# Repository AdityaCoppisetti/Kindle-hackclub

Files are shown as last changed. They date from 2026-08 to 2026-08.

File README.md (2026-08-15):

hey im dhruv coppisetti and i built my own kindle from scratch using a e ink display and my own custom pcb i designed!
i absolutely love e ink displays and have been wanting to build my own kindle from a very long time. 
i dont want something thats too fancy or has too much, a simple kindle type design works aswell.

i love reading books and with all the travelling that im doing, i havent been able to carry my books and i know i could 
just download books on my phone and read them that way but i am just a sucker for single purpose technology. 
and its just so amazing building your own devices and with the hackclub's macondo program i thought i should make this and so i did. 
before this i havent really made much without using what was in my arduino kit. so in this project, i learnt along the way whatever it took me to make this 
and you can learn aswell from my journal.md in this project , i go over almost everything

here is how the kindle i designed looks like 

Screenshot From 2026-08-15 14-37-48

Screenshot From 2026-08-15 14-38-00

Screenshot From 2026-08-15 14-38-12

 i need to answer some questions to explain further why i built this 

1) why am i making this?
  this is a device for students and avid readers like me who want a distraction free reading device     with a long battery life and its open sourced.

2) what makes it different from a kindle?
  its fully open sourced hardware and firmware , its extremely repairable , expandable with a microsd card with customizable software and a secondary oled status display for battery , page nuber and reading progress.

 3) display size - 4.2 inch e ink display 
 4) battery life- target of 3 to 6 weeks of normal reading with aggressive deep sleep and infrequent e ink refreshes
 5) linux or bare metal?
    bare metal sice im using an esp32-c3 ( arduino framework with platformIO) this provides much
    lower power consumption and faster startup than linux
6) touchscreen? no physical buttons only for a distraction free reading
experience and improved battery life.

for this project ill be making my own custom esp32 powered pcb 

which looks like this -





it took me multiple versions of the pcb to come to this point you can find all of that in my journal.md 

here is how the pcb looks like in kicad's 3d viewer





and obviously here is a lil 360 

https://github.com/user-attachments/assets/d5890601-8e93-464f-907f-b951f2e43e23

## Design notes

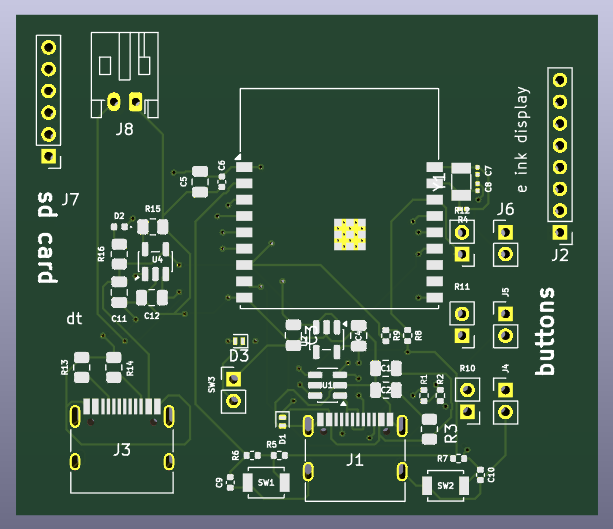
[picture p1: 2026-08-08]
Screenshot From 2026-08-08 19-58-43.png

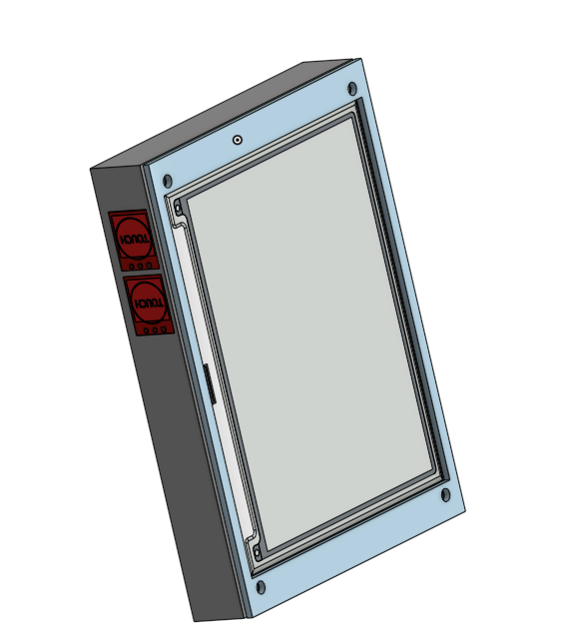
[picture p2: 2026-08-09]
Screenshot From 2026-08-09 17-33-04.png

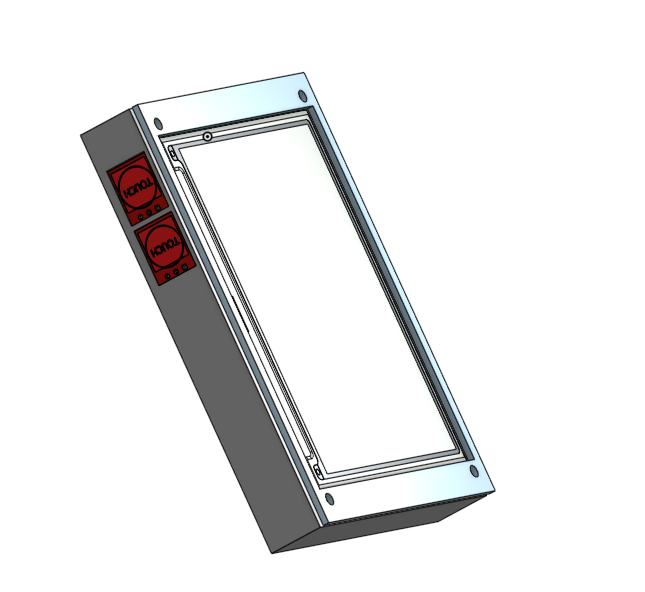
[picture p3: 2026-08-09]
Screenshot From 2026-08-09 17-25-31.png

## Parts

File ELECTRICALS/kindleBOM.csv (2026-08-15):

Reference | KiCad Qty | Value | Footprint | Product | Purchase Qty | Currency | Unit Price | Pack/Line Price | Product Link | in usd
C1,C2,C3,C4,C5 | 25 | 4u7 | C_0805_2012Metric | 4.7µF 0805 SMD capacitor | 10 | INR | 14 | 140 | https://robu.in/product/mc0805f475z160ct-multicomp-pro-cap-smd-mlcc-4-7%c2%b5f-16-v-0805-pack-of-5/ | $1.47
C6 | 1 | C | C_0402_1005Metric | 4.7µF 0402 SMD capacitor | 5 | INR | 6 | 30 | https://robu.in/product/155r61a475meaad-murata-cap-smd-mlcc-4-7-%c2%b5f-10-v-0402-pack-of-1/ | $0.31
C9 | 1 | 4U7 | C_0805_2012Metric | 4.7µF 0805 SMD capacitor | 10 | INR | 14 | 140 | https://robu.in/product/mc0805f475z160ct-multicomp-pro-cap-smd-mlcc-4-7%c2%b5f-16-v-0805-pack-of-5/ | already have
C10 | 1 | 100N | C_0402_1005Metric | 100nF 0402 SMD capacitor | 5 | INR | 0.55 | 2.75 | https://robu.in/product/0402b104k500nt-fh-50v-100nf-x7r%c2%b110-0402-multilayer-ceramic-capacitors-mlcc-smd-smt-rohs/ | $0.03
C11 | 1 | 4.7u | C_0805_2012Metric | 4.7µF 0805 SMD capacitor | 10 | INR | 14 | 140 | https://robu.in/product/mc0805f475z160ct-multicomp-pro-cap-smd-mlcc-4-7%c2%b5f-16-v-0805-pack-of-5/ | already have
D1 | 1 | D | D_SOD-882D | PMEG3002AELD SOD-882D Schottky diode | 5 | INR | 10 | 50 | https://robu.in/product/pmeg3002aeld315-nexperia-30v-480mv200ma-200ma-sod-882d-schottky-diodes-rohs/ | $0.52
D2 | 1 | LED | LED_0402_1005Metric | 0402 red SMD LED | 5 | INR | 1.58 | 7.9 | https://robu.in/product/0402-surface-mount-led-red-50pcs/ | $0.08
J1 | 1 | USB_C_Receptacle_USB2.0_16P | USB_C_Receptacle_G-Switch_GT-USB-7010ASV | G-Switch GT-USB7010ASV USB-C receptacle | 1 | USD | 0.44 | 0.44 | https://jlcpcb.com/partdetail/GSwitch-GT_USB7010ASV/C2988369 | $0.44
J2 | 1 | Conn_01x02 | JST_PH_S2B-PH-K_1x02_P2.00mm_Horizontal | JST PH 2-pin 2.00mm horizontal connector | 5 | USD | 0.68 |  | https://robu.in/product/s2b-ph-klfsn-jst-1x2p-2p-ph-tin-2-25%e2%84%8385%e2%84%83-2a-1-2mm-brass-bend-insert-push-pullp2mm-wire-to-board-connector-rohs/ | $0.68
J3 | 1 | Conn_01x08_Pin | PinHeader_1x08_P2.00mm_Vertical | 1x8 2.00mm pitch pin header | 10 | USD | 0.42 | 4.2 | https://robu.in/product/ds1021-09-1x8sf1-a3-0-b6-0-b-connfly-1x8-pin-2-54mm-pin-header-v-t-type-h2-0mm/ | $0.42
J4,J5 | 4 | Conn_01x06_Pin | PinHeader_1x06_P2.00mm_Vertical | 1x6 2.00mm pitch pin header | 10 | USD | 0.42 |  | https://robu.in/product/ds1021-09-1x8sf1-a3-0-b6-0-b-connfly-1x8-pin-2-54mm-pin-header-v-t-type-h2-0mm/ | $0.42
R1,R2 | 4 | 5K1 | R_0402_1005Metric | 5.1kΩ 0402 SMD resistor | 5 | USD | 0.04 |  | https://robu.in/product/ac0402fr-075k1l-yageo-res-thick-film-0402-5-1k-ohm-1-0-063w1-16w-%c2%b1100ppm-c-pad-smd-t-r-automotive-aec-q200/ | $0.04
R3 | 1 | 0r | R_0402_1005Metric | 0Ω 0402 SMD resistor | 5 | USD | 0.013 |  | https://robu.in/product/erj2ge0r00x-panasonic-100mw-thick-film-resistors-100ppm-%e2%84%83600ppm-%e2%84%83-0%cf%89-0402-chip-resistor-surface-mount-rohs/ | $0.01
R4,R6,R8,R9 | 16 | 10k | R_0402_1005Metric | 10kΩ 0402 SMD resistor | 10 | USD | 0.082 |  | https://robu.in/product/10k-resistor-smdr-0402-pack-of-50/ | $0.08
R5 | 1 | 100r | R_0402_1005Metric | 100Ω 0402 SMD resistor | 2 |  |  |  | https://robu.in/product/1-month-warranty-1125/ | $0.03
R10 | 1 | 470r | R_0402_1005Metric | 470Ω 0402 SMD resistor | 3 | USD | 0.0068 |  | https://robu.in/product/ac0402fr-07470rl-yageo-res-thick-film-0402-470-ohm-1-0-063w1-16w-%c2%b1100ppm-c-pad-smd-t-r-automotive-aec-q200/ | $0.01
R11 | 1 | 470r | R_0805_2012Metric | 470Ω 0805 SMD resistor | 4 | USD | 0.042 |  | https://robu.in/product/rc0805fr-07470rl-yageo-res-thick-film-0805-470-ohm-1-0-125w1-8w-%c2%b1100ppm-c-pad-smd-t-r/ | $0.04
R12,R13,R14 | 9 | R | PinHeader_1x02_P2.00mm_Vertical | 1x2 2.00mm pitch pin header | 5 | USD | 0.42 |  | https://robu.in/product/ds1021-09-1x8sf1-a3-0-b6-0-b-connfly-1x8-pin-2-54mm-pin-header-v-t-type-h2-0mm/ | $0.42
SW1,SW2 | 4 | SW_Push | SW_SPST_B3U-1000P | Omron B3U-1000P SMD tactile switch | 6 | USD | 3.99 | 3.99 | https://robu.in/product/b3u-1000p-omron-2-5mm-1-6mm-round-button-50ma-vertical-welding-3mm-spst-1-53n-12v-smd2-5x3mm-tactile-switches-rohs/ | $3.99
SW3,SW4,SW5,SW6 | 16 | SW_Push | PinHeader_1x02_P2.00mm_Vertical | 1x2 2.00mm connector/header | 7 | USD | 0.23 |  | https://robu.in/product/aa07a09010000006a-bzcn-3a-125v-3a-250v-10000-times-plugin-limit-switches-rohs/ | $0.23
U1 | 1 | USBLC6-2SC6 | SOT-23-6 | USBLC6-2SC6 | 8 | USD | 0.47 |  | https://robu.in/product/usblc6-2sc6-ms-msksemi-4-5a-15v-150w-6v-5v-sot-23-6-esd-and-surge-protection-tvs-esd-rohs/ | $0.47
U2 | 1 | AP2112K-3.3 | SOT-23-5 | AP2112K-3.3 | 9 | USD | 0.94 |  | https://robu.in/product/ap2128k-3-3trg1-diodes-incorporated-300ma-fixed-3-3v-positive-6v-sot-23-5-voltage-regulators-linear-low-drop-out-ldo-regulators-rohs/ | $0.95
U3 | 1 | ESP32-C3-WROOM-02 | ESP32-C3-WROOM-02 | ESP32-C3-WROOM-02 | 10 | USD | 8.15 |  | https://robu.in/product/espressif-esp32-c3-wroom-02-n4-module/ | $8.15
U4 | 1 | MCP73831-2-OT | SOT-23-5 | MCP73831-2-OT | 11 | USD | 5.35 |  | https://robu.in/product/mcp73831t-2aci-ot-microchip-battery-charger-for-1-cell-of-li-ion-li-pol-battery-6v-input-4-2v-500ma-charge-sot-23-5/ | $5.35
BAT1 (external) |  | Lithium battery |  | SP Rechargeable battery (Amazon listing) | 12 | USD | 3.13 |  | https://www.amazon.in/SP-Rechargeable-Connector-Bluetooth-Electronics/dp/B0H568LR23 | $3.13
pcb from jlcpcb |  | pcb |  | pcb | 1 | USD |  | 2
 |  |  |  |  | 1 | USD | 30.61 | 30.61 |  | $30.61
e ink display | 1 | e ink display | none | e ink display | 1 | inr |  | 6040 | https://amzn.in/d/0fYbejic | $63.29
touch buttons | 3 | TTP223 Touch Key Switch Module | none | TTP223 Touch Key Switch Module | 1 | inr |  | ₹228 | https://amzn.in/d/00sZICji | $2.39
 |  |  |  |  |  |  |  |  |  | The total is $120.03 USD.

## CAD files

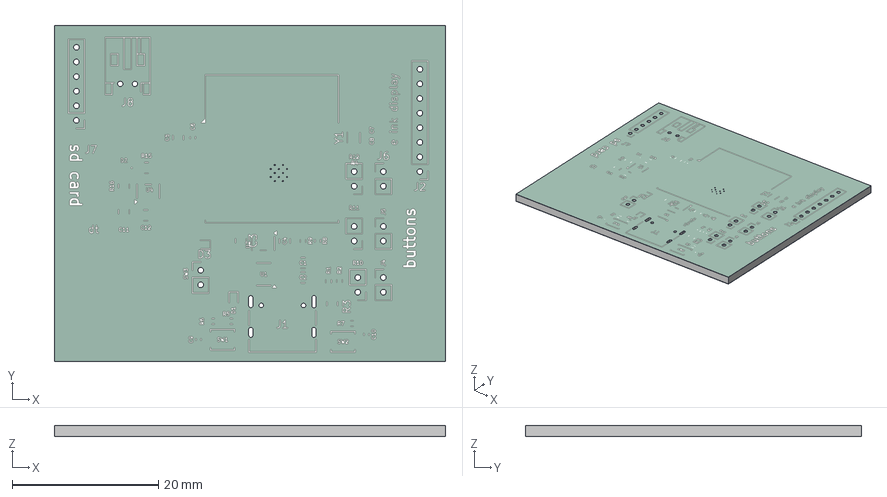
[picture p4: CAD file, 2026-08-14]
CAD/kindle.step
53.5 x 46.0 x 1.64 mm
kindle_silkscreen
kindle_soldermask x 2
kindle_PCB

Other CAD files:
CAD/kindle assembled.step
CAD/TTP223.x_t

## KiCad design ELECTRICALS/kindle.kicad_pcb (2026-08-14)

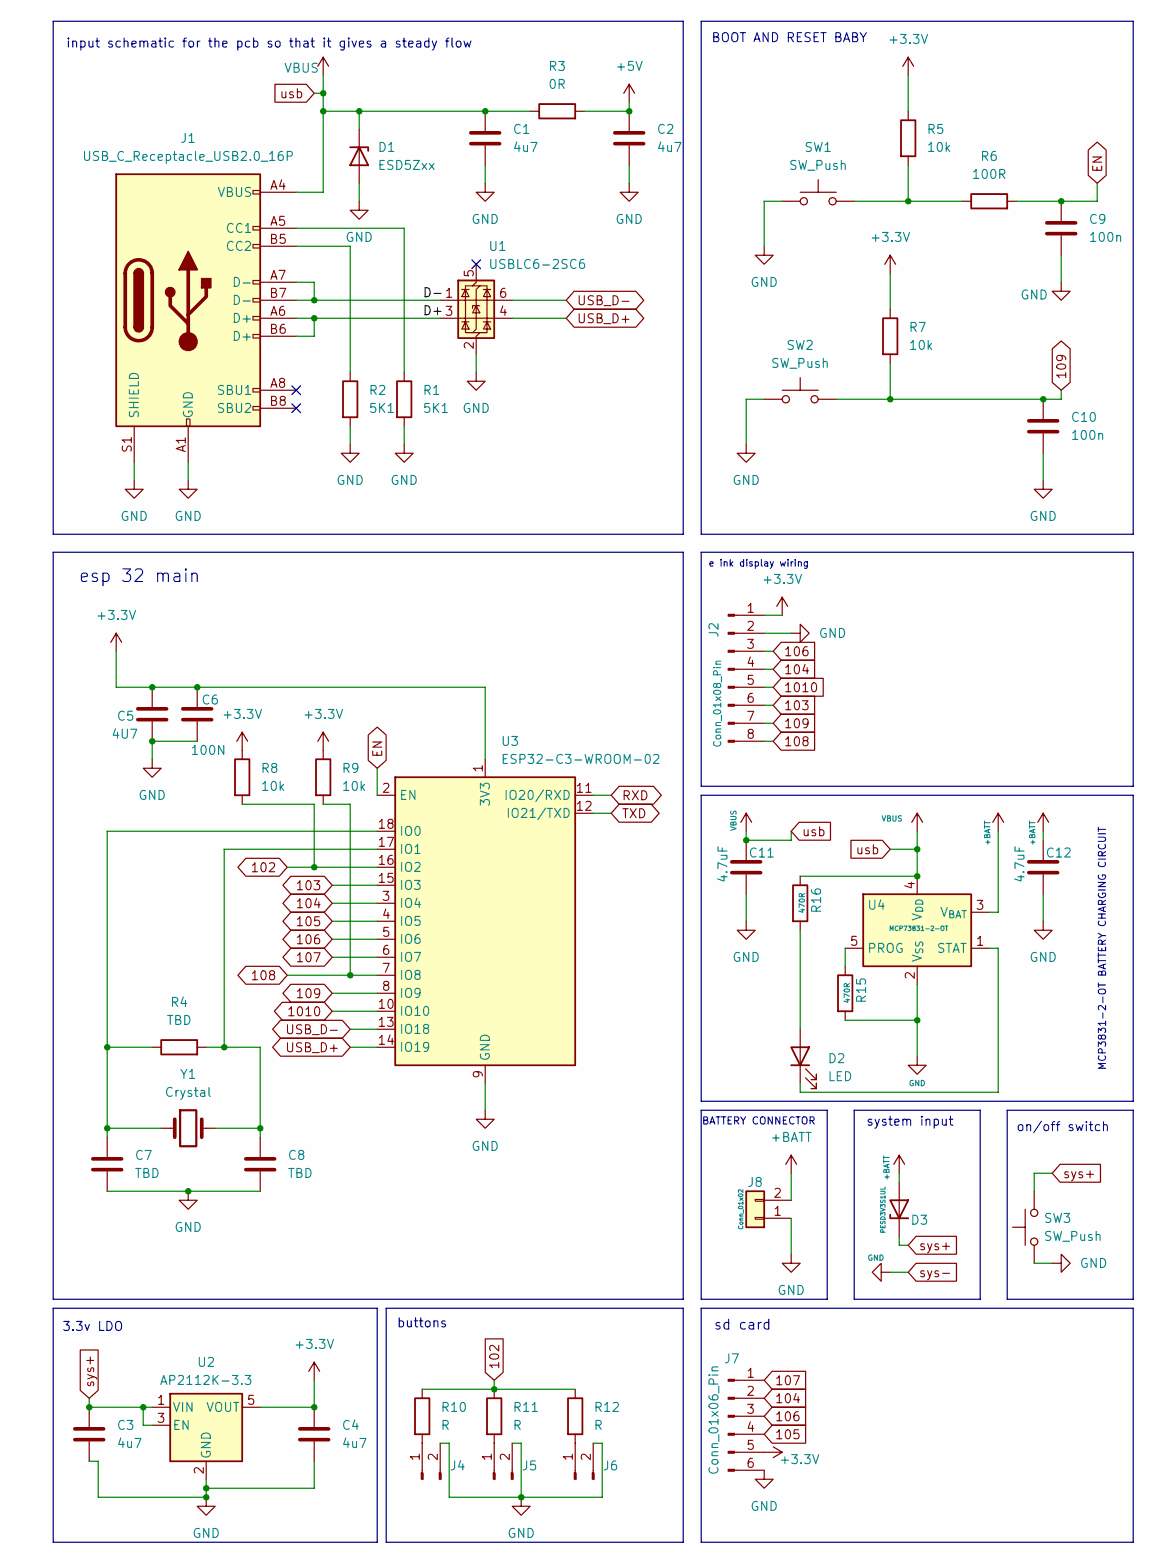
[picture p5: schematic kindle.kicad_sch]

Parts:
C1, C2, C3, C4: 4u7; C_0805_2012Metric
C5: 4U7; C_0805_2012Metric
C6: 100N; C_0402_1005Metric
C7, C8: TBD; C_0201_0603Metric
C9, C10: 100n; C_0402_1005Metric
C11, C12: 4.7uF; C_0805_2012Metric
D1: ESD5Zxx; D_SOD-882D
D2: LED; LED_0402_1005Metric
D3: PESD3V3S1UL; D_SOD-882
J1: USB_C_Receptacle_USB2.0_16P; USB_C_Receptacle_G-Switch_GT-USB-7010ASV
J2: Conn_01x08_Pin; PinHeader_1x08_P2.00mm_Vertical
J4, J5, J6: Conn_01x02_Pin; PinHeader_1x02_P2.00mm_Vertical
J7: Conn_01x06_Pin; PinHeader_1x06_P2.00mm_Vertical
J8: Conn_01x02; JST_PH_S2B-PH-K_1x02_P2.00mm_Horizontal
R1, R2: 5K1; R_0402_1005Metric
R3: 0R; R_0805_2012Metric
R4: TBD; R_0201_0603Metric
R5, R7, R8, R9: 10k; R_0402_1005Metric
R6: 100R; R_0402_1005Metric
R10, R11, R12: R; PinHeader_1x02_P2.00mm_Vertical
R15, R16: 470R; R_0805_2012Metric
SW1, SW2: SW_Push; SW_SPST_B3U-1000P
SW3: SW_Push; PinHeader_1x02_P2.00mm_Vertical
U1: USBLC6-2SC6; SOT-23-6
U2: AP2112K-3.3; SOT-23-5
U3: ESP32-C3-WROOM-02
U4: MCP73831-2-OT; SOT-23-5
Y1: Crystal; Crystal_SMD_3215-2Pin_3.2x1.5mm

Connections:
102: R8.2, R10.1, R11.1, R12.1, U3.16 (IO2)
103: J2.6, U3.15 (IO3)
104: J2.4, J7.2, U3.3 (IO4)
105: J7.4, U3.4 (IO5)
106: J2.3, J7.3, U3.5 (IO6)
107: J7.1, U3.6 (IO7)
108: J2.8, R9.2, U3.7 (IO8)
109: C10.1, J2.7, R7.2, SW2.2, U3.8 (IO9)
1010: J2.5, U3.10 (IO10)
+3.3V: C4.1, C5.1, C6.1, J2.1, J7.5, R5.1, R7.1, R8.1, R9.1, U2.5 (VOUT), U3.1 (3V3)
+5V: C2.1, R3.2
+BATT: C12.1, D3.2 (A), J8.2, U4.3 (V_{BAT})
/D+: J1.A6 (D+), J1.B6 (D+), U1.3 (I/O2)
/D-: J1.A7 (D-), J1.B7 (D-), U1.1 (I/O1)
EN: C9.1, R6.2, U3.2 (EN)
unnamed: D2.2 (A), R16.2
unnamed: D2.1 (K), U4.1 (STAT)
unnamed: J1.A5 (CC1), R1.1
unnamed: J1.B5 (CC2), R2.1
unnamed: J4.1, R10.2
unnamed: J5.1, R11.2
unnamed: J6.1, R12.2
unnamed: R5.2, R6.1, SW1.2
unnamed: C7.1, R4.1, U3.18 (IO0), Y1.1
unnamed: C8.1, R4.2, U3.17 (IO1), Y1.2
unnamed: R15.1, U4.5 (PROG)
RXD: U3.11 (IO20/RXD)
TXD: U3.12 (IO21/TXD)
USB_D+: U1.4 (I/O2), U3.14 (IO19)
USB_D-: U1.6 (I/O1), U3.13 (IO18)
sys+: C3.1, D3.1 (K), SW3.2, U2.1 (VIN), U2.3 (EN)
sys-: C1.2, C2.2, C3.2, C4.2, C5.2, C6.2, C7.2, C8.2, C9.2, C10.2, C11.2, C12.2, D1.2 (A), J1.A1 (GND), J1.A12 (GND), J1.B1 (GND), J1.B12 (GND), J1.S1 (SHIELD), J2.2, J4.2, J5.2, J6.2, J7.6, J8.1, R1.2, R2.2, R15.2, SW1.1, SW2.1, SW3.1, U1.2 (GND), U2.2 (GND), U3.9 (GND), U3.19 (GND), U4.2 (V_{SS})
usb: C1.1, C11.1, D1.1 (K), J1.A4 (VBUS), J1.A9 (VBUS), J1.B4 (VBUS), J1.B9 (VBUS), R3.1, R16.1, U4.4 (V_{DD})

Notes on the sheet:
input schematic for the pcb so that it gives a steady flow
BATTERY CONNECTOR
on/off switch
BOOT AND RESET BABY
3.3v LDO
MCP3831-2-OT BATTERY CHARGING CIRCUIT
system input
buttons
sd card
esp 32 main
e ink display wiring

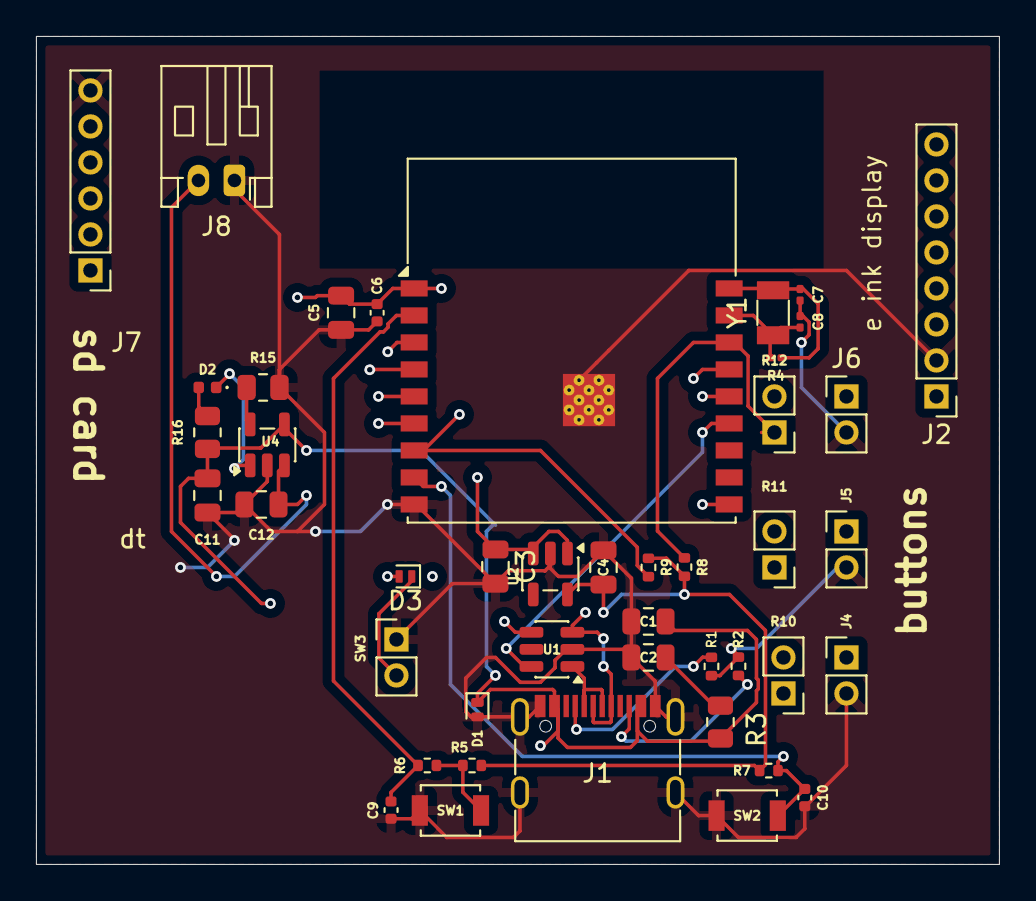
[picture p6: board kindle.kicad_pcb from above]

Board: 4 copper layers, 53.5 x 46.0 mm, 44 parts (0 on the bottom side), 31 nets.

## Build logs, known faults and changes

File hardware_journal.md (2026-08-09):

this is the where i will be journaling my kindle build.

so i had basically made the esp32 for the kindle which would control the entire device.
what i want is to have bluetooth and wifi so i can upload the book wirelessly.

i got the idea from my sony a6000 camera, which has this option to wirelessly and it 
truly is neat because my old camera required me to put it into this giagantic docking system in order to transfer pictures which just annoyed me.

i wanted to get my pcb making skills on a better level so i thought about making my own esp32.
i had alot of trouble with my first design. a total of 71 errors.

here is the list of components i have and their respective footprints. 
althought i do suggest that you do go over them once incase i have done something wrong.

this is the PHASE ONE OF DEVELOPMENT.

**PHASE ONE**
here we will decide how it looks
sketches 
front layout
rear layout
button placement
screen bezels 
thickness
materials
colour

and then phase 2 would be to CAD everthing.



 a total of 29 components.
i really want to make junkier and more intresting looking pcb in the future.

i got a ton of the capacitors wrong so make sure you dont get that wrong.
their footprint needs to be exactly as what you want, you should use the ss i have attached above.



this section of the schematic provides power to the board and enables usb communicatoin via the c type port
between the esp32-c3 and the computer youre using. it handles the usb power input and even protekcs the usb data lines from fluctuation 
and wierd electrocstatic discharge.

why am i using that exact usb type c recepticle-
i have a ton of c type wires lying around and no one has those old micro usb( idek what they were called)
lying around.

whats with the pull down resistors? (R1 & R2)
the usb c requires configuration channel (CC) resistors so that the host recognizes the device correctly
( i lowk really wanna give this board a really funky name bahahaha)

why they are needed-
identify the borad as usb device (sink)
allow the usb host to enable the 5v supply
ensure the compatibility regardless of cable orientation.
without these resistors i dont think the usb-c would provide power.

VBUS ( the 5v)
the vbus line carries the incoming 5v from the usb connector.
it supplies the oboard voltage regulator , supplies the usb 5v header pin.
acts as the primary power source when connected to a computer.

i think that the D10ESD protection diode is very very very important
because the usb connector is exposed to the outside world and is susceptible to electrostatic discharge.
it protects the pcb from static electricity.
diverts voltage spikes safely to ground
helps prevent the damage to the esp32 and usb circuitry.



i actually got these wrong when i did it. so thats why im attaching this picture to make sure the D- and the D+ matches.

the U!-USBLC6-2SC6 protection.
the usb D+ and d- lines are sensitive to voltage spikes 
( which is what i was afraid of happening when i got them wrong
( i accidently reversed their wiring , luckily i spotted it before turning it in)
it protects the the usb data lines form the ESD events
preserves signal integrity.
increases long termreliability of the usb interface.

what are ESD events?

ELECTROSTATIC DISCHARGE events are basically when there are sudden,
momentary flows of electric current betweentwo objects at different electrical potentials, 
occuring via contact electrical short or dielectric berakdowns

(AAAAAAAAAAAAAAAAAAAAAAAAAAAAAAAAA)

C1 and the C2 bulk capatitors-
these capacitors stabalize the incoming supply voltage.
reduce oltage ripple
provide transient current during sudden load charges.

the o ohm resistor-
although it behaves like a wire electrically , the o ohm reisistor provides flexibility in the design.
it allows easy isolation of the usb power rail during testing
can be replaces with a ferrite bead for improved EMI FILTERING
simplifies debugging and future hardware revisings.

next i suggest to do would be the LDO



okay so i have a mistake in my design , the AP2112k-3.3 is a 3.3 V regulator but my VOUT is labeled +5v

it looks like the regulator is outputting 5V which it definitely isnt.
ahhh such a silly mistake.

this is how it should look like- 



i even wired it properly in the pcb editor.



i dont know how to add images on silkscreen i really wanna bombard the entire pcb with silly images.
silly cat images to be exact. i love cats , someone get me a cat.

okay so about the LDO-

the 3.3V Voltage regulation
the esp32-c3 operaties at 3.3v ( which is why it shouldnt be the +5v like i had done) 
while the USB-c connector supplies 5v, therefore a voltage regulator is required to safely power the microcontroller and the other 3.3V components.

the U2-AP2112k-3.3 Low dropout regulator (LDO)
it converts the incoing 5V usb supply into a stable 3.3V output
this then protects the microcontroller from overvoltage.

the C3 - Input Capacitor
the input capacitor filters the incoming 5V supply before it enters the regulator.
it reduces the voltage ripple from the usb supply 
provides instantaneous current during sudden load changes
prevent unwanted voltage fluctuations

C4 is the output capacitor.
the output capacitor stabalizes the regulators 3.3 V output.
maintains the steady 3.3 v supply
imporoves transient response when the esp32 draws aton of current.
prevents oscillation of the voltage regulator 

thats the LDO.
 oh and here is the pcb 3d view of the ldo

 

lets now move onto the the boot and reset!!!!
this is for some reason the funnest part for me idek why.

 I LOVE BUTTONS I LOVE ALL OF EM besides those wierd small metal ones i hate em.

 **BOOT and RESET circuit**
 the boot and reset circuit povides a simple method for resetting the esp32-c3
 and placing it into a bootloader mode for firmware programming. proper control of these pins is very important for debugging, software development and recovery.

 Switch one (SW1)
 this is the reset button.



 the reset button is connected to the En pin ( enable ) of the esp32-c3

 it restarts the microcontroller
 allows the firmware to reboot without disconnecting power
 usefule during firmware development and debugging.
 when the button is pressed the EN pin is pulled LOW resetting the esp32
 realing the button returns the EN pin high , allowing the microcontroller to start executing the      firmware.

 **the R5**
 - 10 kilo ohm pull up resistor- 
 the en pin must remain high during normal operation
 so it holds the en pin at 3.3v during normal operation.
 it prevents the unintended resets caused by the electrical noise.
 ensures reliable startup of the esp32-c3.
 wihtout this resistor the en pin could float causing random or unreliable resets.

**the R6**
100 ohm series resistor 
a small series resistor is placed between the reset circuitry and th EN pin 
it limits transient current during switching
reduces electrical noise on the en line
provides additional protection for the esp32 input
alhtough i do have to say it not always requiered , it imporves the integrity of th signal.

**The C9- 100 nF Capacitor**
the capacitor connected to the EN pin forms a small RC network.
it filters high frequency electrical noise
generated a breif power on delay during startup
improves reset stability and prevents false triggering.
this ensures the esp32-c3 stars reliably whenever power is applied.

boot circuit- the esp32 enters its serial bootloader when the gpio09 is hel low during reset.

NOW ONTO THE BOOOOOOOOT BUTTON!

**the switch 2 ( SW2) which is our boot button.**

the boot push button is connected to the GPIO09
it forces the esp32-c3 into bootloader mode
allows new firmware to be uploaded through usb
provides a manual recovery method if firmware becomes corrupted 
to enter the bootloader mode the boot button is held while the reset button is pressed.

**The R7 10 ohm pull up resistor**
gpio 9 myust normally remain high 
it keeps the boot pin at a logic HIGH during normal operation
prevents accidental entry into bootloader mode.
imporves reliability by eliminating floating inputs.

C10 100 nF Capacitor
a capacitor is connected to the boot pin
reduces electrical noise , it also improves the signal stability during button operation
helps prevent false boot mode detection.

and with that , thats the end of the boot and reset button circuit.



 and this is how they look in the pcb editor.

 

 and then the 3d view , which doesnt really help much but still i love buttons so imma show everything.

 

**now lets get onto the main esp32 core circuit schematic**



the esp32-c3 WROOM 02 module serves as the primary processing unit of the development board
it is responsible for the executing firmware, controlling components , handling the usb and communication and interfacing with the external devices through the gpio pins.
this seectoin of the entire schematic also includes the supporting circuirty required for stanle operantion including power filtering clock generation and signal conditioning.

**U3 esp320c3 wroom - 02**

this the main microcontroller module used in this project
it executes the application firmware 
handles the usb communication and firmware uploading
provides wifi and bluetooth low energy BLE connectivity
controls all the gpio perpherals connected to the development board.

**C5 bulk supply capacitor(4.7uF)**

the esp32 experiences rapid changes in current consumption especially during wireless communication
it stabilizes the 3.3v supply
provides transient current during high power operations
reduces voltage ripple on the power rail

**the C6 decoupling capacitor (100nF)**

the 100nF capacitor is places close to the esp32 power pin
it filters the high frequency electrical noise
provides a local energy reservoir for fast switching currents
improves
power integrity and overall system stability.

**EN pull up resistor (R8)**
the enable pin controls wether the esp32 is running or held in reset.
it hold the en pin high during normal operation
it prevents accidental entry into bootloader mode
works together with the boot push button to enable firmware uploading.

**crystal oscillator (Y1)**
this in my first attempt at the pcb , i didnt place it close enough which was bad. cause it should be AS close to the esp32 module as it can be.

this generates an accurate clock signal 
ensures reliable execution o firmware
supports accurate usb communication
maintains timing accuracy for wireless communication.

**Crystal load capacitors ( c7 and C8)**
the crystal requires external load capacitors to oscillate correctly
it stabilizes the crystal oscillator 
it improves the frequency accuracy
it reduces startup time
it minimizes frequency dirft caused by electrical noise.

SERIES RESISTOR (R4)
a small resistor is placed in the crystal circuit
it contrls oscillator drive strength , it reduces ringing on the crystal signal and it improves oscillator stability when required.
lowk shouldnt i put a 0 ohm resistor instead??

this is the crystal wiring in the schematic editor.



and here is how it looks in the pcb editor 



and here is how it looks in the 3d view



.
.

**USB DATA LINES (USB D+ and USB D-)**

the esp32 includes a native usb full speed controller
it enables the firmware uploading wihtout an external usb to uart converter
it provides usb serial communication
simplifies development by allowing direct programming through usb-c

now onto the gpio layout-



THE MOST IMPORTANT THING HERE IS THAT FOR THE J2 , I.E THE LEFT SIDE GPIO PINS I HAVE REVERSED THE SYMBOL IN THE SCHEMATIC. 

so when youre gonna be wiring do this- 

https://github.com/user-attachments/assets/d0f3d229-0610-4695-a153-af34da82ba7c

which is basically pressing r to rotate it cause yk its upside down.

okay so ive used global label to connect it to the main core , which only makes the schematic neater.

the j2 & 3 and expansion headers 
i did the mistake of accidentally putting the wrong footprint with 9 pins. make sure that doesnt happen.

there are also power pins to supply regulated 3.3v and 5v.
there are also ground pins.

here is how it looks like in the pcb editor.



and then in the 3d viewer it looks like this.



 ALL OF THIS PUT TOGETHER AND ROUTED LOOKS LIKE THIS- 

https://github.com/user-attachments/assets/d6af7f0d-325b-4ab3-99fa-96ceb57c8545

 AND THEN HERE IT IS IN THE 3D VIEWER 

https://github.com/user-attachments/assets/1673bee4-c454-4514-89f8-4a8e1b6599c3

here is the documentation for the tp4056 module i made.
if you want to buy one you can ,
i made it on my own to improve my kicad skills and also because i couldnt find the symbol for it.
( i dont think there is one in the library tho)



so here is the schematic i made -



why even use the tp4056 module-
the lion batteries cannot be directly charged. we need a proper charging module to charge those batteries. the battery charging module provides a safe and reliable method of charging a single cell lithium ion battery using a usb type c pin.

my schematic consists of three primary sections
1) the usb c power input
2) the MCP73831 battery charging cicuit
3) and the battery connector.

**the usb c power input-**
we dont need any data communication just for power so we are using the power only port.



this is the wiring schematic of the usb port. you can use any port you want its upto you,
do rememeber that we will be soldering pogo pins onto the input part of the usb port so that when we make our dock it works. this is how it'll work. 

the usb type c connector serves as the primary power source for the charging circuit. it receives 5v from an external usb charger and supplies it to the battery charging ic.

actually you know what come to think of it how will i wire this to the main esp32 board.

okay okay ill make another version of this module later on let me just explain the schematic rn.

**the J1- usb type c receptacle**
the usb type c receptacle is responsible for delivering power from an external usb source to the charging circuit
it recieves a regulated 5v input (VBUS)
provides a reversible and modern charging interface
supplies power to the mcp73831 charging controller

**the cc1 and cc2 pull down resistors (5.1 kilo ohm)**
the usb type c specification requires configuration channel (cc) resisitors so that the power source 
can correctly identify the connected device.

it identifies the deive as a usb power sink 
requests the default usb power profile
enables the usb power source to provice the 5v supply
supports correct operation regardless of cable orientation.
without these resistors many usb c charges will not enable the vbus output.

THE BATTERY CHARGING CIRCUIT



the battery charging circuit is built is built around the microchip MCP73831 a dedicated single cell lithium lithium ion battery charging controller. the ic automatically manages the charging process using a constand current constant voltage charging algorith to ensure safe and efficient charging.

**U1-MCP7831 Battery charging controller**
the MCP7831 is the central component responsible for charging the lithium ion battery.

it regulated battery charging current 
it performs contant current charging during the initial stage
automatically transitions to constant voltage charging as the battery aproaches full capacity
terminates charging when the battery is fully charged
protects the battery from the overcharging by limiting the charging voltage to 4.2 V

**C1- INPUT CAPACITOR (4.7uF)**
the input capacitor is connected between the usb supply and ground.
this filters noise from the incoming usb supply.
reduces voltage ripple.
improves stability of the charging controller.
supplies instantaneous current during transient load conditions.

**C2- battery output capacitor (4.7 uF)**
the output capacitor is connected across the battery terminals.
it stabilizes the battery voltage during charging.
reduces voltage fluctuations.
improves transient response.
ensures stable operation of the charging controller.

**R1 Programming resistor ( 2 kilo ohm)**
the charging current of the mcp73831 is determined by the resistor connected to the RPOG pin
it sets the maximum charging current.
controls charging speed.
it prevents excessive charging current that could damage the battery.

A 2 kilo ohm resistor configures the charging contrller for an aproximate 500mA charging current.
making it suitable for charging to medium capacity lithium ion cells while maintaining battery life.

**D1 Charging status led**
this idicates when battery chargin is in progress
provides visual feedback during charging
simplifies debugging and testing
during the charging the STAT pin pulls low , illuminating the lef once charging is complete the led turns off automatically

**Current limiting resistor**
a resistor is connected in series with the status led.
it limits the led current, it protects both the led and the STAT output.
It ensures safe and reliable operation of the status indicator.

**BATTERY CONNECTOR**
the battery connector provides the electrical interface between the charging circuit and the lithium ion battery.



**J3 battery connector-**
a two pin connector is used to connect a single cell rechargable lithium ion battery.
it connects the battery to the charging circuit 
it supplies charging current from the MCP73831
delivers stored enegery to the rest of the system during battery powered operation.

the tp4056 module looks somehting like this in the pcb editor ( do keep in mind that this is the version 1, i will be making improvements if i can)



and the 3d view looks like this -



i initially did have trouble when i made this w the routing but my skills were below par.

oh and here are the footprints of the components i forgot to add



okay so here is the version 2 of the battery charger.



this is more compact and i like it.

what i realised when making this again was that- 

my battery charging circuit is only a charging circuit. 
it doesnt know yet that it need to supply the power to the main esp32 motherboard and other components.
its only a charger rn. not a supplier.

my schematic is missing an output.

maybe i will have to redesign it entirely again 

then i added an output for the main motherboard 



UGHHHHHH IM DONE WITH TODAY MAN.

today is july 4th 2026 i am weird.

this is my progress and what all i need to do ( i used chatgpt to mock this up for me)



okay so basically this is just a reference picture from pintrest but this is basically how the wiring will be.



JUNE 10th 2026
time: 11.21 

today i built the case that ill be using for the kindle. its pretty simple

https://github.com/user-attachments/assets/fab1bd39-cfa8-41e5-a1af-e8d5fe0700c8

i also added a diode in the tp4056 output port becuase i think there might be chances of reverse flow of electricity if im flashing the esp32.

Screenshot From 2026-07-10 23-39-51

https://github.com/user-attachments/assets/507f960a-0b0f-4a0c-8c4c-c04210ba8e09

and then this is the footprints once again make sure they're okay



## august 8th
okay so i redesigned the entire pcb 
becuase the last pcb was a clutter and it was just a esp32 and nothing else like i obviously could do better than that -



the flaws with this design- 
1) i can do much better
2) there are exposed gpio pins which means i would have to solder on pin headers which would increase the width of the entire kindle
3) there isnt a onboard lithium battery charger or connector.
4) its just plain ugly

and so i redesigned it into this- 



all i need to do is to solder buttons and the sd card module. i lowkey wanted to add the sd card module onto the board itself
but i couldnt find a schematic of it. 

oh and i cant believe i forgot this but i somehow did not add a on/off switch.

after i added all that i realised that i could just wire all of my buttons using just one pin.
how you may ask, the trick is simple. 
each button is paired with a resistor of different values and when pressed it sends a different voltage and thus its unique from the other buttons. 
i have 3 buttons connected that way.



this is the wiring of the buttons 

and then onto the onboard lithium battery charging module. 

a little bit ago i made a lithium charging module for my tapfolio project and so i used it's schematic 

it looks like this- 

# the schematic 



 its quite dainty!

 # the pcb design 

 

# the pcb design but in 3d 

https://github.com/user-attachments/assets/0aca132c-dafb-493a-ad08-5e09888600b9

go to my tapfolio repo for more info about this pcb!

however i didnt want it to be a seperate pcb and i would have to solder it to connect.
so i just made it onto the board itself 

and so i made the entire schematic of the charging module in the kindle schematic



which is also put together and super dainty.

okay so i updated the pcb again , the on/off switch wasnt connected and the wiring for the charging module was done a bit wrong 

it looks like this now 



also i went ahead and made the refrences alot neater because in all of my other designs the refrences were all over the place and overlapping like crazy

all i need to do now is design the case

## august 9th 
i designed the case!!

i got on onshape and i deisgned the case.
the case isnt really anything pretty but its functional 
yesterday i designed the pcb again and it is much much better and now i designed a mid case bahahaha

okay so here is what i designed- 


i added one big rectangle hole at the side so i can put my usb cables thru it. ill try to make it so there is only two cables.

oh wait i just looks at the schematic and realised that i dont really need to have another usb type c just to charge and so im gonna update the pcb

okay so i changed the pcb- 



okay so i made it so that the pcb just needs one usb input. 
this is still however not the full design. 

anyways back to the case 

i added these 2 holes to put the touch capacitive button into and then i added a lill support beam , i plan to to use those 2 buttons as next and previous page navigation 



also i changed the size of this big hole because the pcb now only needs 1 usb input. 



oh and this is for the select/ main menu button 



it seems that ive forgot to add a lil hole for the on/off switch

now ive added this lil hole beside the type c port so that i can put a on/off switch

oh and with the help of my friend i added fill zones 
and now my pcb looks like this 



and in 3d it looks like this 

Screenshot From 2026-08-09 15-48-49

oh and here is a lil 360 

Screenshot From 2026-08-09 15-48-49

oh and i did this thing with my tapfolio project where i exported my pcb and put it in onshape and deisgned a full mockup in it so im gonna do exactly that

okay so creating the mockup , i insert my touch capacitive module AND HOLY SHIT ITS A PERFECT FIT IM SO IMPRESSED 



okay i guess i got too excited, 
i apparently did the measurements wrong 



now isnt that just so much better

okay so once again i made a mistake so here is the new and improved structure 



i went ahead and added these little cylindrical supports to screw in and tighten the e ink display



well the new case looks perfect!



okay so let me show it to you properly 



here is how it looks like from the inside and outside , dont worry i will be printing them in the same colour 

okay so now let me make the new mockups 

the pcb will be inside the case like this 



and here is how the touch capacitive buttons look like in the case , honestly if i werent using them this case would be so much slimer 



here is how it looks like with the e ink display



and this 

Screenshot From 2026-08-09 17-25-31

here is a better view - 

https://github.com/user-attachments/assets/f9ec9295-9fb2-489a-a745-02fc49c565c6

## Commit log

2026-07-10 Add files via upload
    the kindle case
    [Part Studio 1.x_t]
2026-08-08 Update README with device feature specifications
    Added additional details about the device features including buttons and microcontroller.
2026-08-14 Rename kindle aseembled.step to kindle assembled.step
    [kindle assembled.step]
2026-08-15 Revise README to remove initial questions and details
    Removed introductory questions and descriptions about the device's purpose and features.
